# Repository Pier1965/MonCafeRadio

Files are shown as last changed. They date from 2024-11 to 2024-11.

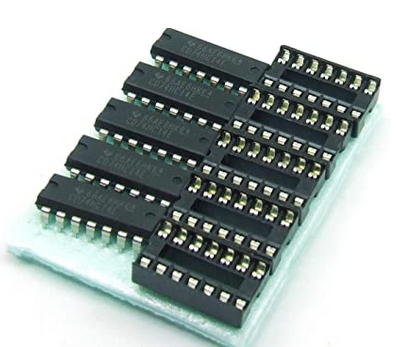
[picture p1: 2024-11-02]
Docs/Bom/img/74HC14.png

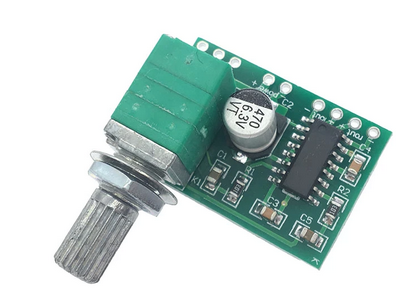
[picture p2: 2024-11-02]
Docs/Bom/img/PAM8432.png

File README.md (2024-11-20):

# MonCafeRadio
Esp32 web/FM radio
---------------

This is a esp32 based web radio.
All the hardware requirements, schematics and pinout, can be fount in the Docs subfolders.
All the drawings for a suitable 3D printed case, in openscad format, can be found
in the Docs/drawings directory.

Settings
--------
The following files could/should be altered in order to personalize the compilation
process. This latter can been performed relying on VS code and the Platformio plugin:
- include/HWsettingsDefine.h (define HW preferencies: screen model, use of a relay
	to switch on and off audio ampli, infrared remote control model); 
- platformio.ini (set the esp32 model);
- include/gpio.h (for different pinout configuration);
- include/define.h (change OLED dimensions and pinout, enable use of NEXTION touch);
- nclude/ir_butt.h (setting the IR remote control);
- include/preproDefine.h (to set debug option);
- include/GlobalVar.h (to set a different ntp server);
- include/GlobalObject.h line 16 (to set the local time zone).

First run
---------
With the working mode switch (clock/radio) in clock position,
at the first start the radio will act as an Access Point with
the name "WebRadioAP". Connect to it and go to the address
192.168.1.4 where SSID and password of the home wifi can be set.
SSID and password can be changed anytime in clock mode pushing
the volumeUp button.

List of radios managing
-----------------------
At the first start a few stations will be available. The list of stations
can be altered by accessing the address of the radio,
readable on the OLED screen by means of a browser.
Stations can be:
- added;
- deleted singularly and in group;
- reordered moving each station in a new position in list;
- swapped in position;
- searched via key word search querying https://www.radio-browser.info/
- the list created can be exported in json format;
- a list can be inported in json format.

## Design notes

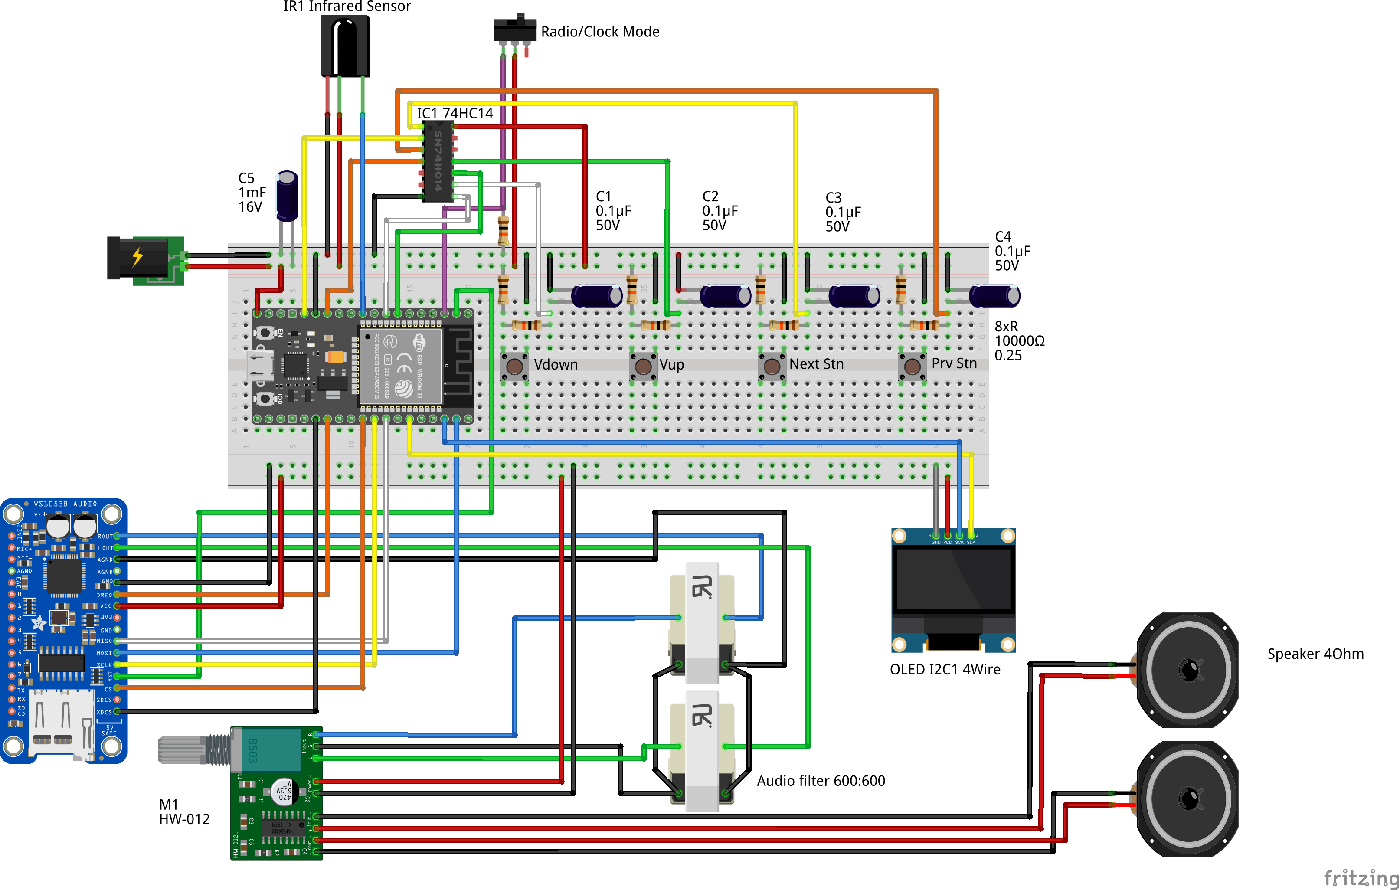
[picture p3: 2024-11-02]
Docs/Bom/img/Schematic.png

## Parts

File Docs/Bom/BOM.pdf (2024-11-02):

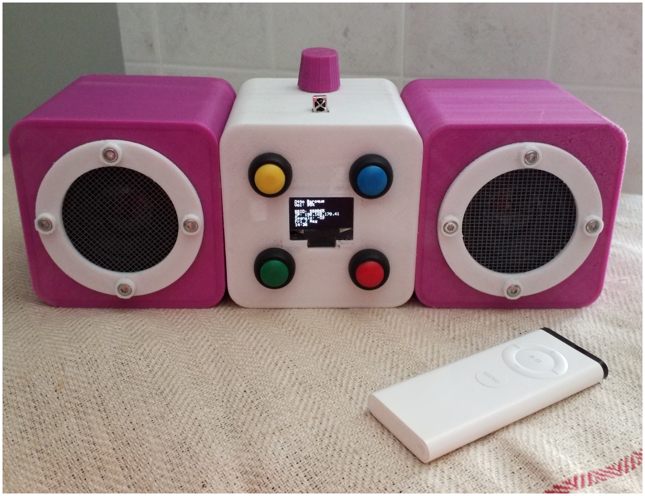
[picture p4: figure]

# N-th Web Radio

# Bill of Materials

Q.ty | Description | Picture | Link

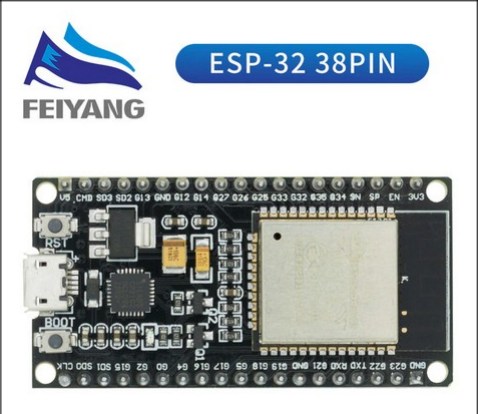
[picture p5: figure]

n.1 | ERP32 Wroom | | ESP32 (https://it.aliexpress.com/item/32864722159.html?spm=a2g0s.9042311.0.0.27424c4dDjW3SZ)

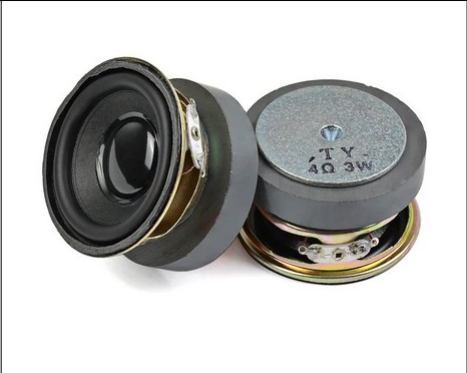
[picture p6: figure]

N.2 | AIYIMA 2 PCS 4ohm 3 W | | Loudspeaker 4Ohm (https://it.aliexpress.com/item/32912123079.html?spm=a2g0s.9042311.0.0.27424c4dL3zYdo)

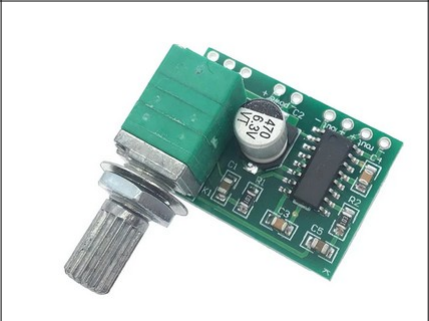
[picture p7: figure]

N.1 | PAM8403 | | Amplifier (https://it.aliexpress.com/item/966217332.html?spm=a2g0s.9042311.0.0.27424c4dr9aevu)

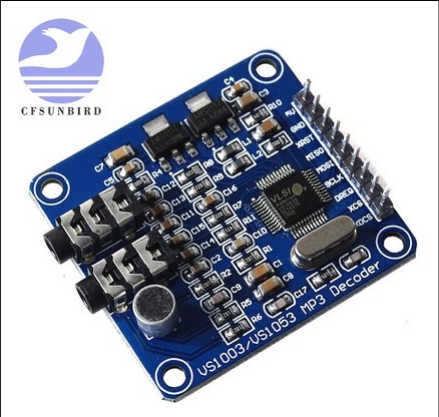
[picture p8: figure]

N.1 | VS1003B VS1053 | | Mp3 chip (https://it.aliexpress.com/item/4001146067436.html?spm=a2g0s.9042311.0.0.27424c4dr9aevu)

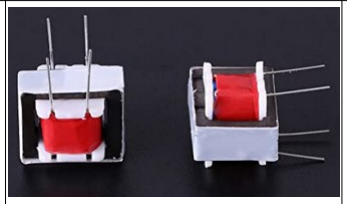
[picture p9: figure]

N.2 | Audio transformer T 1:1 / 600:600 | | Audio filters (https://www.amazon.it/gp/product/B08JCWNKHQ/ref=ppx_yo_dt_b_asin_title_o06_s00?ie=UTF8&psc=1)

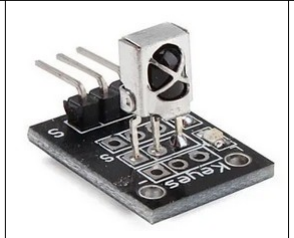
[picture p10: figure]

N.1 | IR Sensor | KY-022 IR (https://it.banggood.com/KY-022-Infrared-IR-Sensor-Receiver-Module-p-916178.html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)

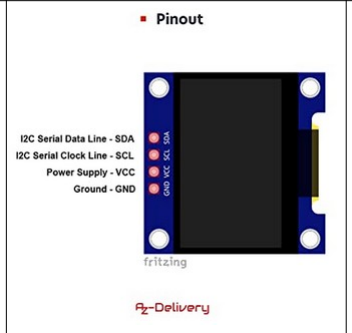
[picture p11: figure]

N.1 | OLED 128x64 4 wire | OLED 1306 (https://www.amazon.it/gp/product/B074N9VLZX/ref=ppx_yo_dt_b_asin_title_o03_s00?ie=UTF8&psc=1)


N.1 | HC74C14 Triggered NOT gate | 74HC14 (https://www.amazon.it/gp/product/B07DT37Y85/ref=ppx_yo_dt_b_asin_title_o07_s00?ie=UTF8&psc=1)


N.1 | Electrolytic capacitor: 1mF x 16V | 1mF Capacitor (https://www.amazon.it/gp/product/B07MNZRBRQ/ref=ppx_yo_dt_b_asin_title_o05_s00?ie=UTF8&psc=1)


N.4 | Electrolytic capacitor: 0.1umF x 16V | 1mF Capacitor (https://www.amazon.it/gp/product/B07MNZRBRQ/ref=ppx_yo_dt_b_asin_title_o05_s00?ie=UTF8&psc=1)


N.9 | Resistor 10KOhm 0.25W | Resistors (https://www.amazon.it/dp/B071Z66XDV?aaxitk=a59ea1286d5f9834aeef6317356b4ac4&hsa_cr_id=2948124570102)


N.4 | Push buttons | Push buttons (https://www.amazon.it/gp/product/B06XCSB9N3/ref=ppx_yo_dt_b_asin_title_o06_s00?ie=UTF8&psc=1)


N.1 | 5.5mm Power supply jack | 5.5 mm Jack (https://hobbyking.com/en_us/2-1mm-5-5mm-dc-chassis-socket-jack-2pc.html?___store=en_us)


N.1 | Switch Radio/Clock mode | Switch (https://www.amazon.it/NATEE-Interruttore-Levetta-Bilanciere-TEN1021/dp/B082B2HCNF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)

# Schematic


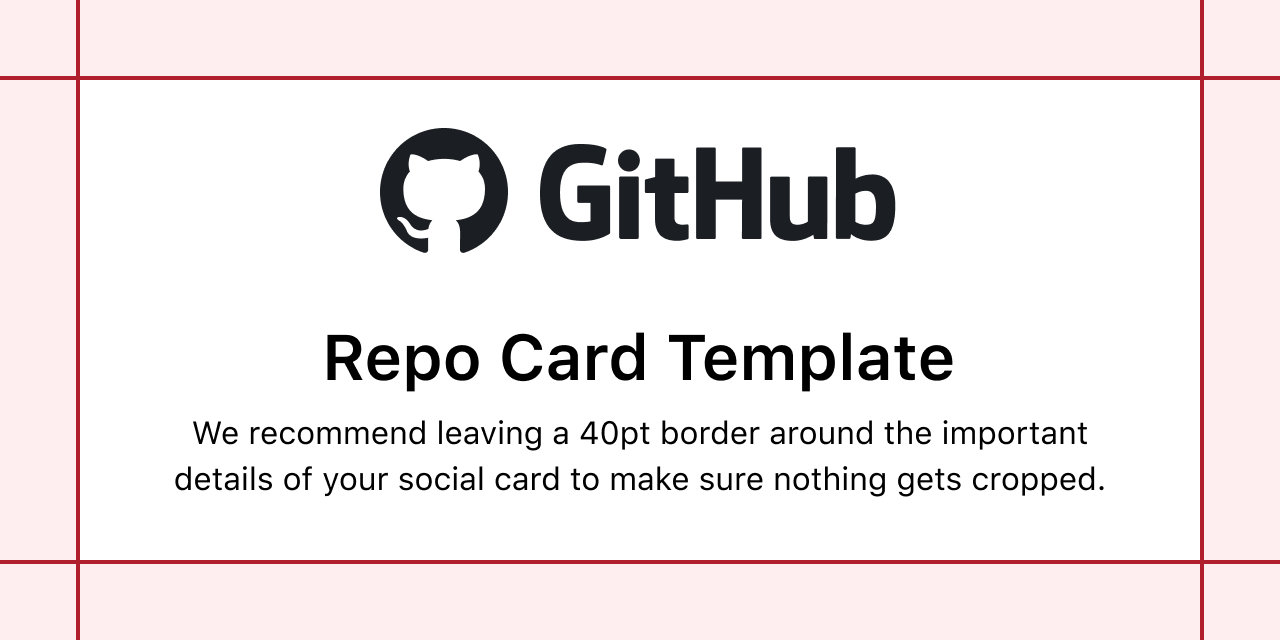
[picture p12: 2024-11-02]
Docs/Bom/img/Radio.png

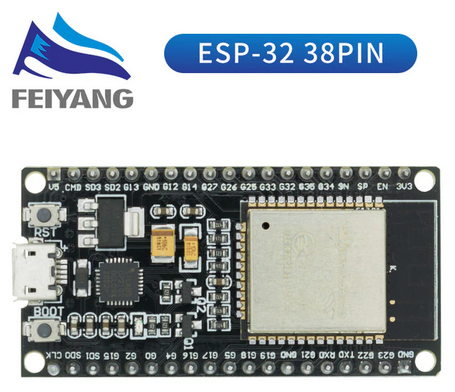
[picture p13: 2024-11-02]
Docs/Bom/img/esp32-wroom.png

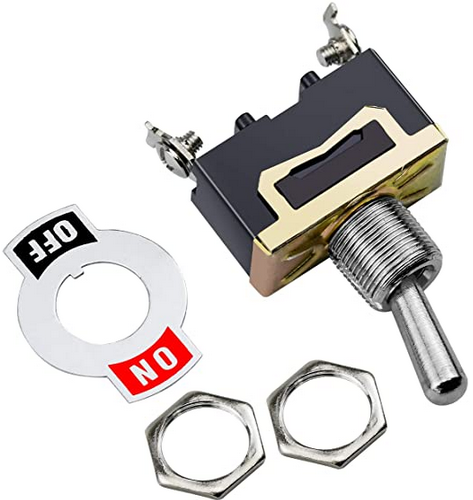
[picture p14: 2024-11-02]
Docs/Bom/img/interruttore.png

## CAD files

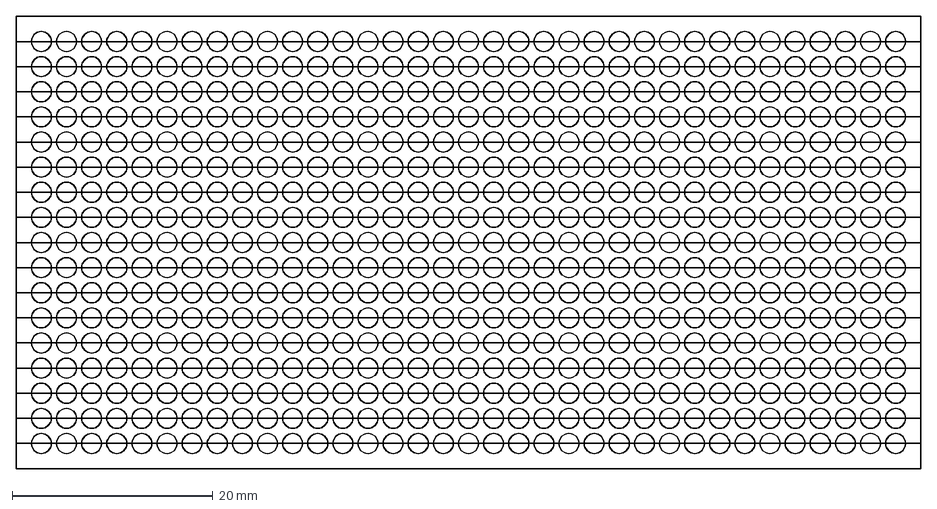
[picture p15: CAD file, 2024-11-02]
Docs/drawings/basetta.dxf
90.0 x 45.0 mm

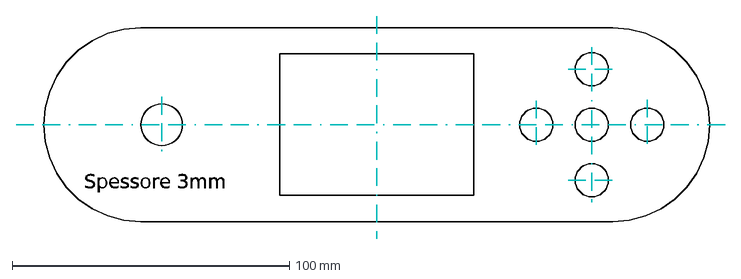
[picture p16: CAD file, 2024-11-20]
Docs/drawings/Case_Cornet_beer/~placcaPulsantieraDisplay_proiezione.dxf
Spessore 3mm

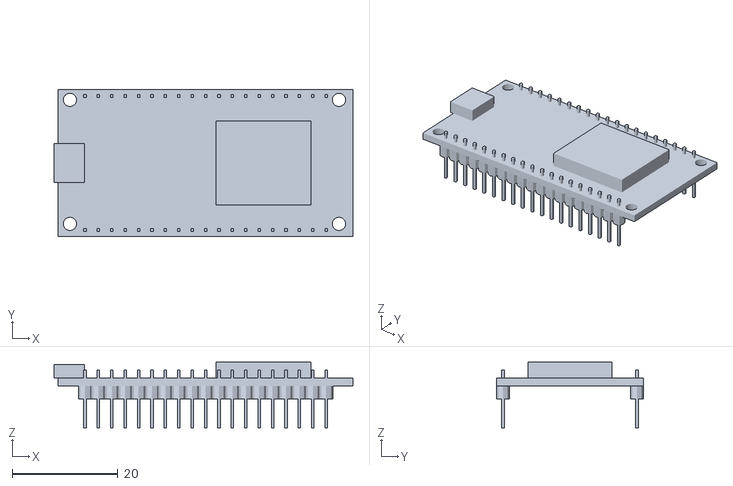
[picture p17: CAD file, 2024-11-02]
Docs/drawings/Case_tre_moduli/esp32_wroom.stl
56.7 x 27.9 x 12.5

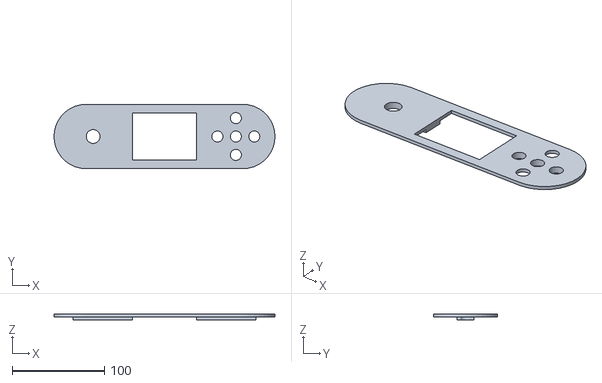
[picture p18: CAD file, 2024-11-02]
Docs/drawings/Case_Cornet_beer/placcaPulsantieraDisplay.stl
240.0 x 70.0 x 6.00

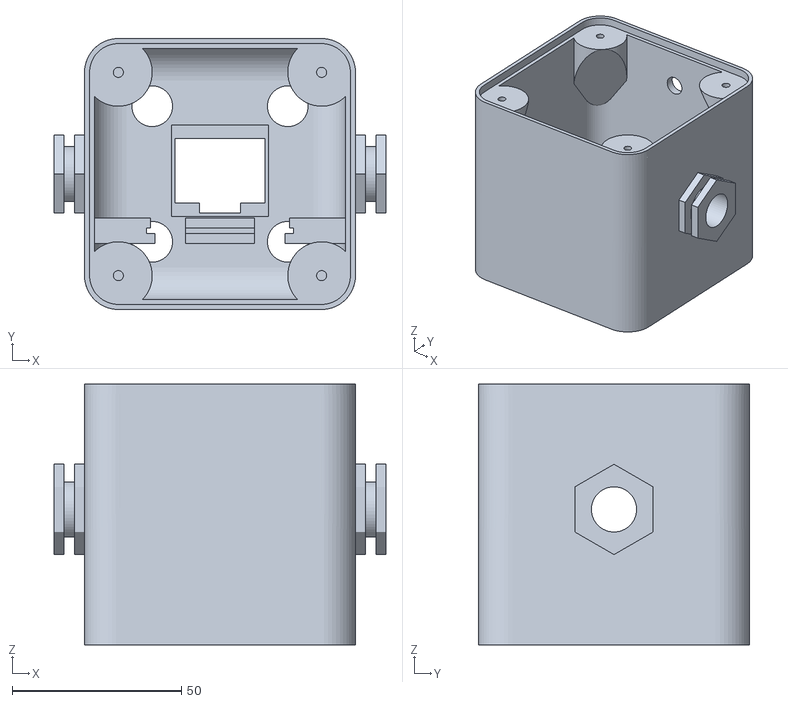
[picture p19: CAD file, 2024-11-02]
Docs/drawings/Case_tre_moduli/case_small.stl
98.0 x 80.0 x 77.0

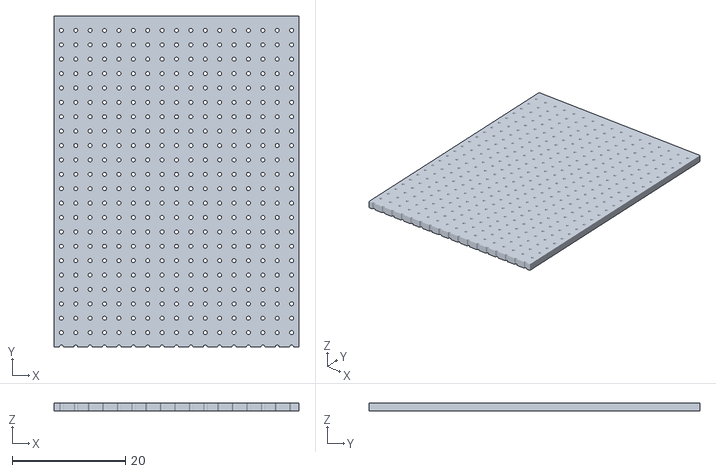
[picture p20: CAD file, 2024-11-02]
Docs/drawings/Case_tre_moduli/millefori.stl
43.2 x 58.4 x 1.50

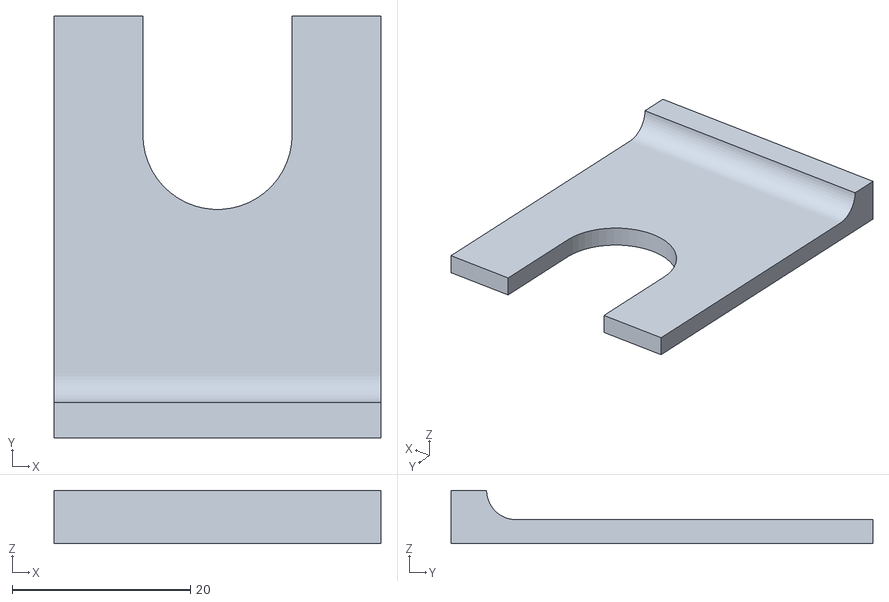
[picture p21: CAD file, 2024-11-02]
Docs/drawings/Case_tre_moduli/forchetta.stl
36.7 x 47.3 x 6.00

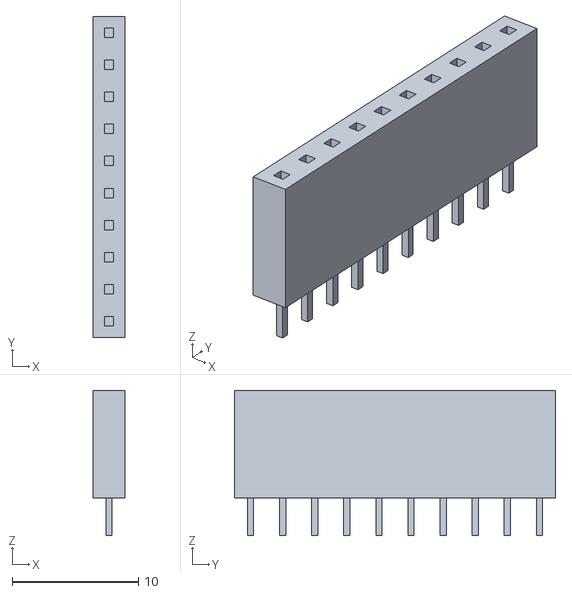
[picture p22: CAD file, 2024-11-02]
Docs/drawings/Case_tre_moduli/dupont.stl
2.54 x 25.4 x 11.5

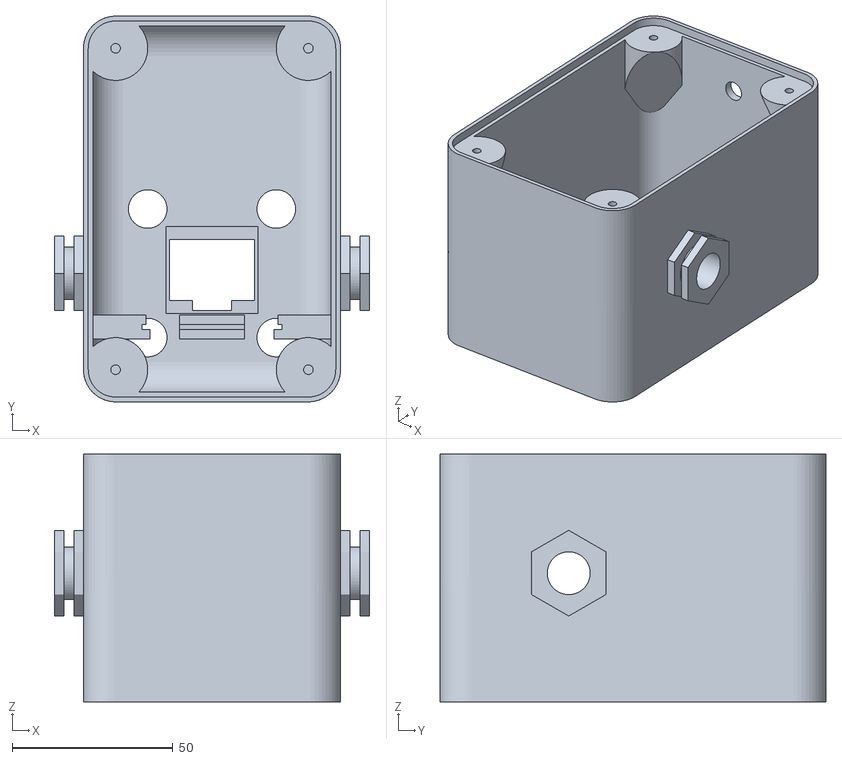
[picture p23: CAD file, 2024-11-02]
Docs/drawings/Case_tre_moduli/case-large.stl
98.0 x 120.0 x 77.0

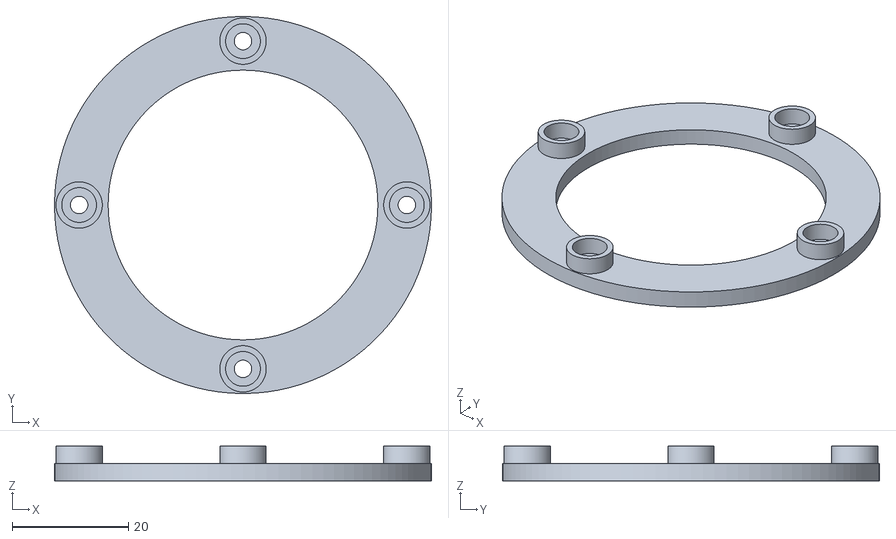
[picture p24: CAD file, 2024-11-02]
Docs/drawings/Case_tre_moduli/anello.stl
65.0 x 65.0 x 5.99

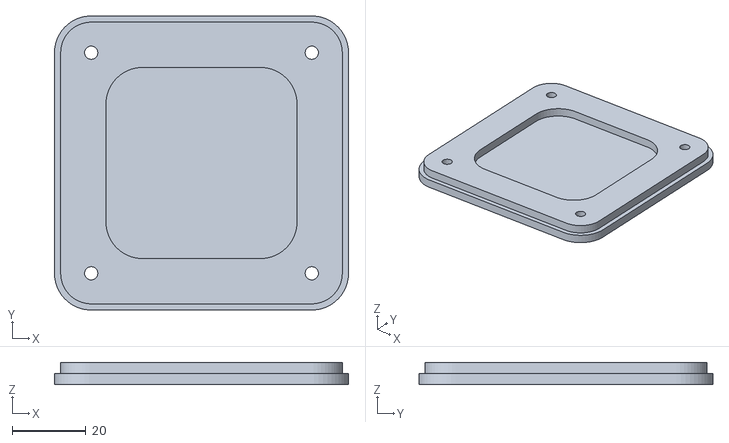
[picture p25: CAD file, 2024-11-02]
Docs/drawings/Case_tre_moduli/tappo-cassa.stl
80.0 x 80.0 x 6.00

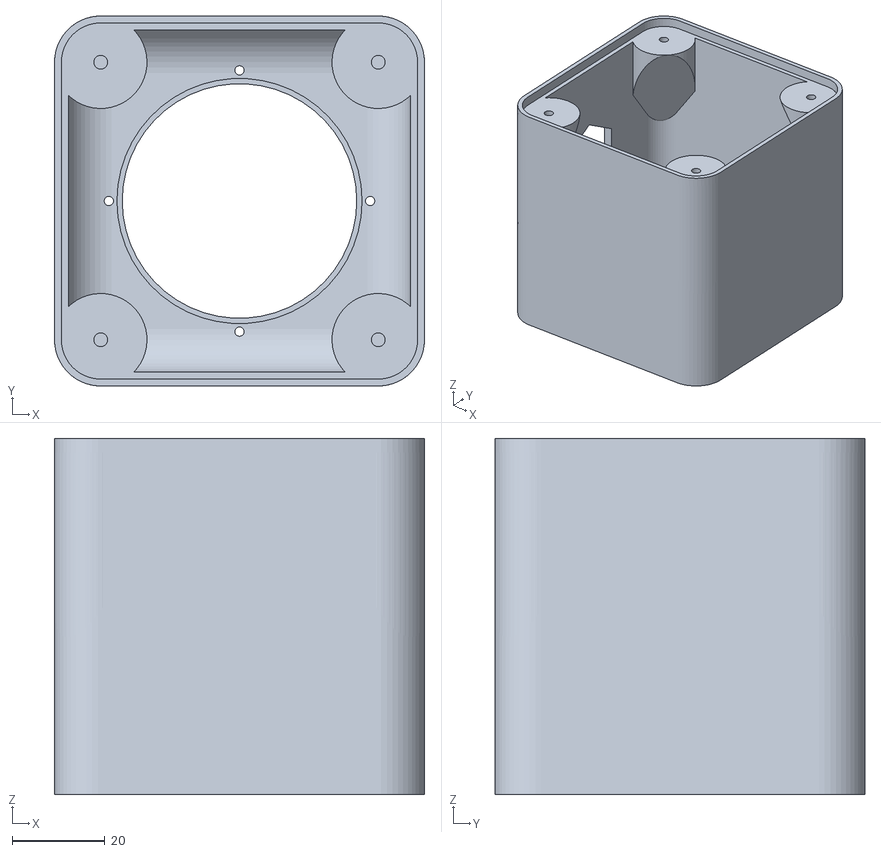
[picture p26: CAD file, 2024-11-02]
Docs/drawings/Case_tre_moduli/cassa.stl
80.0 x 80.0 x 77.0

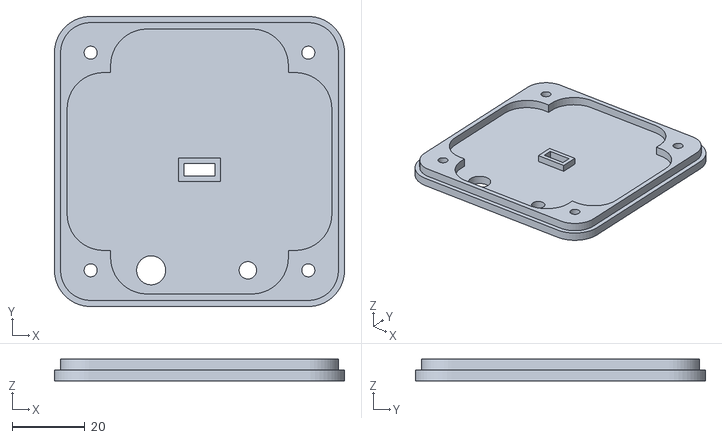
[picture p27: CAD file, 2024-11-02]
Docs/drawings/Case_tre_moduli/tappo-case.stl
80.0 x 80.0 x 6.00

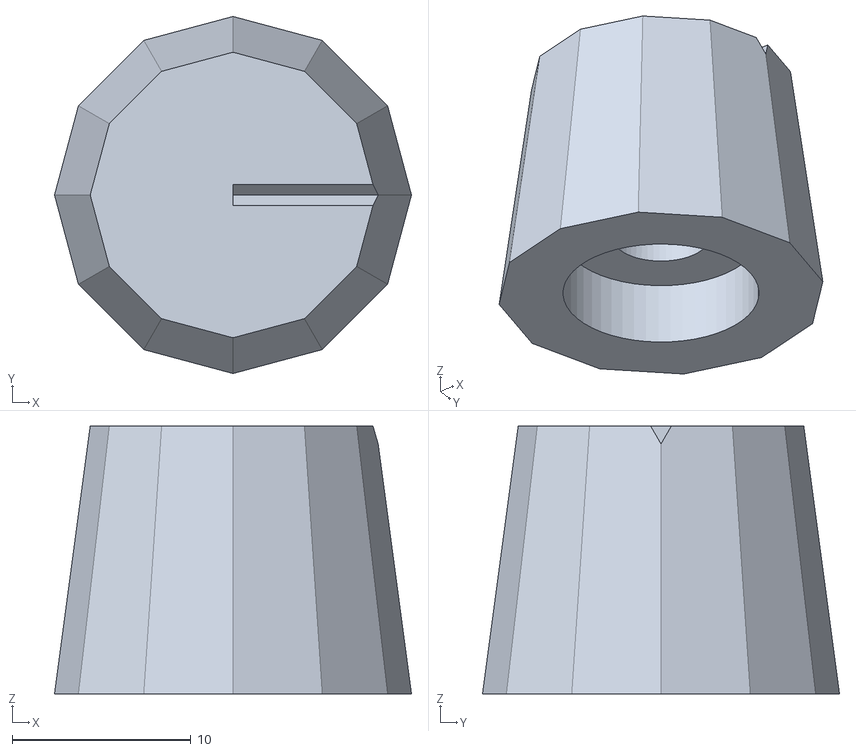
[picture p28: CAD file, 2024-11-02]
Docs/drawings/Case_tre_moduli/knob.stl
20.0 x 20.0 x 15.0

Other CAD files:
Docs/drawings/Case_tre_moduli/Gcode/WDI3_cassa.3mf
Docs/drawings/Case_tre_moduli/Gcode/WDI3_case.3mf
Docs/drawings/Case_tre_moduli/Gcode/WDI3_forchetta.3mf
Docs/drawings/Case_tre_moduli/case.stl
Docs/drawings/Case_tre_moduli/pin.scad
Docs/drawings/Case_Cornet_beer/placcaPulsantieraDisplay.scad
Docs/drawings/Case_Cornet_beer/placcaPulsantieraDisplay_proiezione.scad
Docs/drawings/Case_tre_moduli/anello.scad
Docs/drawings/Case_Cornet_beer/placcaPulsantieraDisplay_proiezione.dxf
Docs/drawings/Case_tre_moduli/Assembly.scad
Docs/drawings/Case_tre_moduli/case-0.0.scad
Docs/drawings/Case_tre_moduli/case.scad
Docs/drawings/Case_tre_moduli/case_small.scad
Docs/drawings/Case_tre_moduli/cassa-0.0.scad
Docs/drawings/Case_tre_moduli/cassa.scad
Docs/drawings/Case_tre_moduli/dupont.scad
Docs/drawings/Case_tre_moduli/esp32_wroom.scad
Docs/drawings/Case_tre_moduli/esp8266mod.scad
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

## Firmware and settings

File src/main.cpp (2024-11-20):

/*
  Web radio con ESP32

  Pierpaolo Garofalo - http://pier.unirc.eu
  Licensed under GNU GPL v3
 //=================================================================================
27/04/2021
1) Gestisce immissione cambio stazioni e volume tramite pulsanti HW con debouncing SW e HW  (v)
2) Memorizza Stazion e Volume in eeprom                                                     (v)
Otto baroque si sente a volte bene e a volte con singhiozzo a buffer 64, con 32 pare liscio
28/04/2021
3) Interfaccia OLED con info rete e canale                                                  (v)
4) Telecomando IR di vari tipi per cambio stazione e volume                                 (v)
5) Orario e data in OLED                                                                    (v)
01/05/2021
6) Modalità radio oppure orologio
08/05/21
7) Pare risolta questione BBC #208 https://www.youtube.com/watch?v=aMS4XwEr8s0&t=51s
  Nei commenti di random sporadic projects
  Fine 2023 BBC è passata a HSL :-(
8) Aggiunto digit a orari inferiori alle 9
09/05/2021
9) Modificata gestione ora. Se l'orario è stato ottenuto in avvio da NTP non usiamo di nuovo la connessione alla rete
10) Multiwifi per connettersi a piu reti wifi e riconnessione corretta nel caso si perda il collegamento
10/05/21
11) Quando si cambia modalità da Clock a Radio riconnettere wifi e stazione e viceversa
12/05/2021
12) Implementato ring buffer per risolvere Otto Baroque a 320kbps che balbetta... pare funzionare
04/05/2022
    Ringbuffer e abbandonato sia con libreria originale (mio metodo) che librerie di Cellies (disabilitare PSRAM)
    a causa dei continui buffer underrun con Komsomolskaia Pravda
    Gennaio 2024
13) Aggiunta gestione tasti da 0-9 IR con telecomandi che li prevedono (Elegoo)
14) Aggiunta gestione SSID e passwordtramite portale AP 192.168.4.1: in modalità clock
    schiacciare il pulsante VolUp e collegarsi alla rete WebRadioAP e impostare SSID e password di rete
    08/02/2024
15) Eliminato l'hard code di SSID e Password: tolto multiwifi e messo wifimanager
    09/02/2024
16) OLED, IR, Tasti, e modalità di funz OK
    6/02/2024
17) Correzione aggiornamento della data ora locale che non prevedeva il settaggio LOCALE
18) Passaggio alla libreria
      baldram/ESP_VS1053_Library
      celliesprojects/ESP32_VS1053_Stream@^2.0.6 -> La RAI si risente con queste ... boh
      con cellies però il ring buffer continua a dare underrun con Radio Komsomolskaia
    Eliminato hard coding delle stazioni radio:
    Gestione inserimento stazioni via html: webserver e websocket
    Gestione della lista di radio con funzioni aggiungi, sposta ecc
    Passaggio a platformio con board wrover e wroom
    15/03/2024
19) Gestione tasti telecomando per doppia cifra
    21/03/2024
20) Gestione visualizzazione html ottimale per dispositivi
    17/03/2024 (parziale)
21) Gestione ricerca radio con api Radio-Browser
    https://www.radio-browser.info/
    21/03/2024
22) Aggiunto telecomando IR TANIX smart TV, e KC-808
    22/03/2024
23) Aggiunta possibilità di impostare stazione e volume da browser
    via lista comandi a tendina
    27/03/2024
24) Aggiunta la possibilità di esportare la lista delle radio in formato Json
    ListaRadio.json
    28/03/2024
25) Aggiunta la possibilità di importare la lista delle radio in formato Json
    Per gestire file di dimensione maggiore di 1346b, in WebServer.h
    riga 38)  #define HTTP_DOWNLOAD_UNIT_SIZE 3*1436
    riga 41)  #define HTTP_UPLOAD_BUFLEN 3*1436
    01/04/2024
25)	Aggiunto schermo touch NEXTION NX4832T035_011
  	25/04/2024
26) Aggiunto schermo OLED a colori 2.8" ST7789
	Sostituita levetta di modalità di funzionamento con un pulsante
	o con il tasto di spegnimento rosso del telecomando
	Aggiunto un rele che spegne l'amplificatore audio in modalità orologio
	Aggiunto il telecomando Zodiac
  	01/11/2024
27) Risolto problema grafico che 2.8" da con NODEMCU Wroom forse per scarsa memoria
  riscrivendo la funzione di cancellazione schermo a rettangolini. Lasciata anche per 
  WROVER che a volte non cancellava bene sfondo.
    13/11/2024
28) Aggiunto ritardo ad riaccensione ampli dopo spegnimento per evitare bump casse
    14/11/24
Da fare
    Aggiungere radio FM con secondo esp32 slave
    Aggiungere verifica sulla coerenza dei dati Pos.1 Pos.2 immessi per la modifica
    della lista di radio.
    Evitare che all'upload della lista di radio si passi alla
    pagina /upload
    Impostare schermo OLED con caratteri grandi indicazione volume e stazione
    durante cambio stazione e volume
    xx/xx/xx
//=================================================================================
*/
#include "preproDefine.h"
#include "HWsettingsDefine.h"
#include "define.h"
#include "GlobalVar.h"
#include "includeLib.h"
#include "GlobalObject.h"
#include "includeFun.h"
//=================================================================================

void setup()
{
  #ifdef HWRCampli
    DEBUG_PRINTLN("Spengo amplificatore SETUP");
    digitalWrite(HWRC, MODEAMPOFF);
    offTimer = millis();
  #endif
  #ifdef SPION
    Serial.begin(115200);
  #endif
  // Config pin del selettore modalità di funzionamento
  confSelector();
  // Setup schermo : Strano... se messo dopo setupInt fa incartare l'ascolto
  #ifdef SCREEN
    initSCR();
    delay(1000);
  #endif
    // Inizializzazione del NEXTION se usato
  #ifdef NEXTOUCH
    nexExists = initNex();
  #endif
  // Avvio del wifi. Se non c'è una configurazione ESSD e PW avvia AP su 192.168.1.4
  // per immettere i valori di rete e ip della radio via browser
  // Se non vengono immessi attende 120 sec, va in timeout e si riavvia.
  //=================================================================================
  #ifdef SCREEN
    printSCR_attesaWL();
  #endif
  if (!wifi_connect())
  {
    DEBUG_PRINTLN("Non Connesso...");
    DEBUG_PRINTLN("ESP si riavvia...");
    delay(5000);
    ESP.restart();
  }
  // Inizializzazione del file system SPIFF
  //=================================================================================
  if (!SPIFFS.begin(true))
  {
    DEBUG_PRINTLN("File system SPIFF non montato... riavvio");
    delay(5000);
    ESP.restart();
  }
  else
  {
    DEBUG_PRINTLN("File system SPIFF montato!!!!!!!");
  }
  // Inizializzazione file delle radio in un oggetto json
  //=================================================================================
  if (!initRadioFileList())
  {
    DEBUG_PRINTLN("File radio non inizializzato... riavvio");
    delay(5000);
    ESP.restart();
  }
  // Inizializzazione e gestione del web server
  // Invio della pagina principale che accetta richieste GET con i campi di input
  //=================================================================================
  startServer();
  DEBUG_PRINTLN("HTTP server e webSocket started");
  // Recupero dell'ora dal server NTP
  //=================================================================================
  initTime();
  restoreEeprom();
  // Inizializzo il decoder Mp3
  //=================================================================================
  SPI.begin();
  SPI.setHwCs(true);
  SPI.begin(SPI_CLK_PIN, SPI_MISO_PIN, SPI_MOSI_PIN); /* start SPI before starting decoder */
  DEBUG_PRINTLN("SPI avviato");
  if (!stream.startDecoder(VS1053_CS, VS1053_DCS, VS1053_DREQ))
  {
    DEBUG_PRINTLN("Cannot start decoder mp3");
    while (1)
      delay(100);
  }
  DEBUG_PRINTLN("Decoder mp3  avviato");
  if (!stream.isChipConnected())
  {
    DEBUG_PRINTLN("Decoder not connected");
    while (1)
      delay(100);
  };
  DEBUG_PRINTLN("Decoder running");
  delay(100);
  // Setup delle routine di interrupt per i tasti stazone e volume
  //=================================================================================
  setupInt();
  // Inizializza sensore IR
  //=================================================================================
  StartIR();
  delay(100);
  /*
      DEBUG_PRINT("codec: ");
      DEBUG_PRINTLN(stream.currentCodec());
      DEBUG_PRINT("bitrate: ");
      DEBUG_PRINT(stream.bitrate());
      DEBUG_PRINTLN("kbps");
  */
  //
  // Se la levetta è in modalità orologio spegni il wifi
  //=================================================================================
  // Sostituzione della levetta bistabile con un pulsante: all'accensione
  // parto sempre in modalità clock
  //WMode = workingMode();
  WMode = false;
  oldWMode = WMode;
  DEBUG_PRINT("WMode = ");
  DEBUG_PRINTDEC(WMode);
  DEBUG_PRINTLN("");
  if (!WMode)
  {
    DEBUG_PRINTLN("Disconnessione e spegnimento WiFi...");
    WiFi.disconnect(true);
    WiFi.mode(WIFI_OFF);
    #ifdef SCREEN
        updateTimeScr();
    #endif
    #ifdef NEXTOUCH
        updateTimeScr_nex();
    #endif
  }
  else
  {
    #ifdef HWRCampli
      DEBUG_PRINTLN("Accendo amplificatore");
      unsigned long attesa = millis() - offTimer;
      if( attesa < Tdebump)
        delay(Tdebump - attesa + 100);
      digitalWrite(HWRC, MODEAMPON);
    #endif
    stream.setVolume(VOLUME);
    JsonObject record = radioRecords[STATION].as<JsonObject>();
    if (record.containsKey(POS2))
    {
      url = record[POS2];
    }
    stream.connecttohost(url);
    DEBUG_PRINT("codec: ");
    DEBUG_PRINTLN(stream.currentCodec());
    DEBUG_PRINT("bitrate: ");
    DEBUG_PRINT(stream.bitrate());
    DEBUG_PRINTLN("kbps");
    #ifdef SCREEN
        updateSCR();
    #endif
    #ifdef NEXTOUCH
        updateSCR_nex();
    #endif
  }
  oldWMode = WMode;
}
// Loop
//=================================================================================
void loop()
{
  server.handleClient();
  webSocket.loop();
  //WMode = digitalRead(RCSelector);
  // Gestione del cambio della modalità di funzionamento
  // RADIO <-> CLOCK
  //=================================================================================
  if (oldWMode != WMode)
  {
    DEBUG_PRINTLN("Modalita funz cambiata");
    oldWMode = WMode;
    // CLOCK -> RADIO
    //=================================================================================
    if (WMode)
    {
      DEBUG_PRINTLN("Modalita radio");
      // Accendo l'ampli audio
      #ifdef HWRCampli
        DEBUG_PRINTLN("Accendo amplificatore");
        unsigned long attesa = millis() - offTimer;
        if( attesa < Tdebump)
          delay(Tdebump - attesa + 100);
        digitalWrite(HWRC, MODEAMPON);
      #endif
      // Riaccendo il WIFI
      #ifdef SCREEN
        printSCR_attesaWL();
      #endif 
      if (!wifi_connect())
      {
        DEBUG_PRINTLN("Non Connesso...");
        DEBUG_PRINTLN("ESP si riavvia...");
        delay(100);
        #ifdef SCREEN
                updateAPSCR(TIMEOUT);
        #endif
        delay(5000);
        ESP.restart();
      }
      delay(100);
      // Ripristino volume e stazione
      stream.setVolume(VOLUME);
      record = radioRecords[STATION].as<JsonObject>();
      if (record.containsKey(POS2))
      {
        url = record[POS2];
      }
      // Tentativo di connessione alla stazione radio
      while (!stream.connecttohost(url))
      {
        // Da fare: qui devo gestire il caso di mancata connessione a TUTTE le radio
        // in elenco... es i++ ad ogni ciclo fino a NR e poi riavviare?
        DEBUG_PRINTLN("Host non connesso");
        DEBUG_PRINTLN("Cambio stazione");
        delay(1000);
        // Qui gestisco la mancata connessione
        // vedo se l'ultimo cambio di stazione è stato in avanti
        // o in dietro e così cerco nella stessa direzione
        if (nxtButton == 1)
        {
          STATION < (NR - 1) ? STATION++ : STATION = 0;
        }
        else
        {
          STATION > 0 ? STATION-- : STATION = NR - 1;
        }
        updateEeprom();
        record = radioRecords[STATION].as<JsonObject>();
        if (record.containsKey(POS2))
        {
          url = record[POS2];
        }
        DEBUG_PRINTDEC(STATION);
        DEBUG_PRINTLN();
        #ifdef SCREEN
                updateSCR();
        #endif
        #ifdef NEXTOUCH
                updateSCR_nex();
        #endif
      }
      delay(500);
      #ifdef SCREEN
            updateSCR();
      #endif
      #ifdef NEXTOUCH
            updateSCR_nex();
      #endif
    }
    else
    {
      // RADIO -> CLOCK
      //=================================================================================
      // Se si è passati in modalità CLOCK spengo il wifi
      // e cancello l'istanza dello stream
      // Spengo l'amplificatore audio
      #ifdef HWRCampli
        DEBUG_PRINTLN("Spengo amplificatore");
        digitalWrite(HWRC, MODEAMPOFF);
        offTimer = millis();
      #endif
      DEBUG_PRINTLN("Disconnessione e spegnimento WiFi...");
      stream.stopSong();
      WiFi.disconnect(true);
      WiFi.mode(WIFI_OFF);
      #ifdef SCREEN
            updateTimeScr();
      #endif
      #ifdef NEXTOUCH
            updateTimeScr_nex();
      #endif
    }
  }
  //=================================================================================
  // Gestione funzionamento in mdalità RADIO
  if (WMode)
  {
    jsonString = "";
    serializeJson(jsonDoc_tx, jsonString);
    while (WMode)
    {
      server.handleClient();
      webSocket.loop();
      // Rimedio al fatto che non riesco a far caricare la lista al caricamento
      // della pagina
      currentWsMillis = millis();
      if (currentWsMillis - startWsMillis > updateWsTime)
      {
        webSocket.broadcastTXT(jsonString);
        startWsMillis = currentWsMillis;
      }
      // Gestione radio in modalità playing
      stream.loop();
      delay(5);
      // check dei comandi NEXTION
      #ifdef NEXTOUCH
            if (nexExists)
              nexLoop(nex_list);
      #endif
      // Check dei tasti e dei comandi IR
      checkIR();
      switch (checkButtons()){
        case STNCH:
          stream.stopSong();
          delay(1000);
          record = radioRecords[STATION].as<JsonObject>();
          if (record.containsKey(POS2))
          {
            url = record[POS2];
            DEBUG_PRINTLN(url);
          }
          // Gestione eventuale mancata connessione
          // e cambio del canale. Da gestire mancata connessione a tutti
          // i canali
          while (!stream.connecttohost(url))
          {
            // L'host non è disponibile... cambio canale
            DEBUG_PRINTLN("Host non connesso");
            delay(1000);
            // Qui gestire la mancata connessione
            if (nxtButton == 1)
            {
              STATION < (NR - 1) ? STATION++ : STATION = 0;
            }
            else
            {
              STATION > 0 ? STATION-- : STATION = NR - 1;
            }
            updateEeprom();
            record = radioRecords[STATION].as<JsonObject>();
            if (record.containsKey(POS2))
            {
              url = record[POS2];
            }
          }
          updatePlayAndVolumeHtml();
          DEBUG_PRINTDEC(STATION);
          DEBUG_PRINTLN();
          #ifdef SCREEN
                  updateSCR();
          #endif
          #ifdef NEXTOUCH
                  updateSCR_nex();
          #endif
          break;
        case VOLCH:
          stream.setVolume(VOLUME);
          DEBUG_PRINTDEC(VOLUME);
          DEBUG_PRINTLN();
          #ifdef SCREEN
                  updateSCR();
          #endif
          #ifdef NEXTOUCH
                  updateSCR_nex();
          #endif
          updatePlayAndVolumeHtml();
          break;
      }
      if (checkTime())
      {
      #ifdef SCREEN
              updateSCR();
      #endif
      #ifdef NEXTOUCH
              updateSCR_nex();
      #endif
      }
    }
  }
  else
  {
    //=================================================================================
    // Funzionamento in modalità CLOCK
    DEBUG_PRINTLN("Orologio");
    while (!checkReset())
    {
      // Gestione radio in modalità orologio
      if (checkTime())
      {
      #ifdef SCREEN
              updateTimeScr();
      #endif
      #ifdef NEXTOUCH
              updateTimeScr_nex();
      #endif
      }
      // In modalità CLOCK schiacciando Volume Up si richiede
      // l'avvio del portale 192.168.4.1 per la gestione
      // del SSID e PW wifi
      if (digitalRead(volumeUp) == HIGH)
      {
        #ifdef SCREEN
                updateAPSCR(TIMEOUT);
        #endif
        delay(100);
        setSsidPw();
      }
    }
  }
}

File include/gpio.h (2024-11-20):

/*
Wiring:
  ---------------------
  | VS1053  |  ESP32  |
  ---------------------
  |   SCK   |  IO18   |
  |   MISO  |  IO19   |
  |   MOSI  |  IO23   |
  |   XRST  |  EN     |
  |   CS    |  IO5    |
  |   DCS   |  IO0    |
  |   DREQ  |  IO4    |
  |   5V    |  5V     |
  |   GND   |  GND    |
  ---------------------

  ---------------------------
  | JMDO 96C-1 OLED | ESP32 |
  ---------------------------
  | SDA             | 21    |
  | SCL             | 22    |
  | GND             | GND   |
  | 5V              | 5V    |
  ---------------------------

  ------------------------------------
  | TFT 2.8 ST7789  | Wroom/Wrover-b |
  ------------------------------------
  | SDA             | 21    | 
  | SCL             | 22    |
  | RST             | 15    |
  | DC              | 27    |
  | CS              | 16/2  |
  | BL              | 14    |
  | GND             | GND   |
  | VCC             | 3.3V  |
  ---------------------------


  ---------------------------
  | IR module elegoo | ESP32 |
  ---------------------------
  | G                | GND   |
  | R                | 5V    |
  | Y                | G26/13|  wroom/wrover - B ttgo
  ----------------------------

  -----------------------------
  | Pulsanti         | ESP32  |
  -----------------------------
  | Vol UP           | G32    |
  | Vol Down         | G33    |
  | Next Station     | G13/34 | wroom/wrover - B ttgo
  | Prv Station      | G12    |
  | Radio-Clock Sel  | G36/35 | wroom/wrover - B ttgo
  ----------------------------

  ------------------------------
  | Rele comando amplificatore |
  ------------------------------
  | G14/26                     |
  ------------------------------

  Il file NexHardware.cpp va modificato per l'uso con seriale 2 del WROVER 

  // Modifica per usare la seriale 2 su wrover-b TTGO
    	#define RXD2 25
		  #define TXD2 26
*/

const int previousButton  	= 12;
#ifdef WROVER
  const int nextButton      = 34;
#endif
#ifdef WROOM
  const int nextButton      = 13;
#endif
const int volumeUp        	= 32;
const int volumeDown      	= 33;
#ifdef WROVER
  const int RCSelector   		  = 35; // Selettore modalità radio o clock Wrover
  #ifdef HWRCampli
    const int HWRC              = 26; // Output comando relè spegnimento ampli audio
  #endif
#endif
#ifdef WROOM
  const int RCSelector   		  = 36; // Selettore modalità radio o clock Wroom
  #ifdef HWRCampli
    const int HWRC              = 17; // Output comando relè spegnimento ampli audio
  #endif
#endif
//IR sensor
//Infrarosso collegato a Pin Esp32
#ifdef WROVER
  const unsigned int kRecvPin		= 13; //26;
#endif
#ifdef WROOM
  const unsigned int kRecvPin		= 26;
#endif
// Pin decodificatore mp3 VS1053
#ifdef ARDUINO_ARCH_ESP32
	#define VS1053_CS     5
	#define VS1053_DCS    0
	#define VS1053_DREQ   4
	#define SPI_CLK_PIN 18
	#define SPI_MISO_PIN 19
	#define SPI_MOSI_PIN 23
#endif

// Pin ST7789
#ifdef ST7789
  #define TFT_SDA 21
  #define TFT_SCL 22
  #define TFT_RST 15
  #define  TFT_DC 27
  #ifdef WROVER
    #define  TFT_CS 2
  #endif
  #ifdef WROOM
    #define  TFT_CS 16
  #endif
  #define  TFT_BL 14
#endif
/*
 ---------------------------
  | TFT 2.8 ST7789  | ESP32 |
  ---------------------------
  | SDA             | 21    |
  | SCL             | 22    |
  | RST             | 15    |
  | DC              | 27    |
  | CS              | 16/2  |
  | BL              | 14    | back light pin
  | GND             | GND   |
  | VCC             | 3.3V  |
  ---------------------------
*/

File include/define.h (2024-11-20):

///////////////////////////////////////////////////
// Rilascio versione software
#define RelDate "Novembre 2024"
#define Autore "Pierpaolo Garofalo"
#define eMailAutore "ing.pierpaolo.garofalo@gmail.com"
#define buildFor "Moncafe Bar Lanciano"
// incremento volume click
#define DVOL 5
// Valori ritornati da cambio stazione o volume
#define STNCH 1
#define VOLCH 2
// gestione valori in flash eeprom
// memorizziamo STATION e VOLUME
#define EEPROM_SIZE 2
// Tempo attesa riaccensione dopo spegnimento per evitare bump casse
#define Tdebump 10000
#ifdef SCREEN
	#ifdef OLEDJMDO
		#define SCREEN_WIDTH 128 // OLED display width, in pixels
		#define SCREEN_HEIGHT 64 // OLED display height, in pixels
		// Declaration for an SSD1306 display connected to I2C (SDA, SCL pins)
		// The pins for I2C are defined by the Wire-library.
		// On an arduino UNO:       A4(SDA), A5(SCL)
		// On an arduino MEGA 2560: 20(SDA), 21(SCL)
		// On an arduino LEONARDO:   2(SDA),  3(SCL), ...
		// Esp32:   SDA -> G21, SCL -> G22
		#define OLED_RESET     4 // Reset pin # (or -1 if sharing Arduino reset pin)
		#define SCREEN_ADDRESS 0x3C ///< See datasheet for Address; 0x3D for 128x64, 0x3C for 128x32
	#endif	
	#ifdef ST7789
		#define SCREEN_WIDTH 320 // OLED display width, in pixels
		#define SCREEN_HEIGHT 240 // OLED display height, in pixels
	#endif
#endif
// Upate time screen in modalità clock
#define UPDATETMRSCR 5000
// Timeout access point e connessione
#define TIMEOUT1 10
#define TIMEOUT 120
// Codifica tasti di telecomandi a infrarossi
#include "ir_butt.h"
// Campi del file info radio
#define POS1 "pos" 		// "field1"
#define POS2 "stream" 	// "field2"
#define POS3 "nome" 	// "field3"
#define POS4 "genere"	// "field4"
